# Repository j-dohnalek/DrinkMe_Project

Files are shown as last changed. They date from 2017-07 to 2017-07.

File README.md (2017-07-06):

# DrinkMe
Drink Me - The talking coaster to support dementia patients. The idea to this started in March 2017 when at a university based hackathon Hacking Health. The idea was pitched by
Hillary Tetlow.

## Idea
One of the issues for people with dementia is the limited short term memory capacity. The memory problem can lead to forgetting to drink leading to reduced water intake and dehydration. The dehydration leads to further problems often leading to hospitalisation.

## Proposed Solution
The solution to this problem would be a talking coaster. The coaster would speak to the person reminding them to drink.

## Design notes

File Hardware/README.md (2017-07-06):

# Hardware

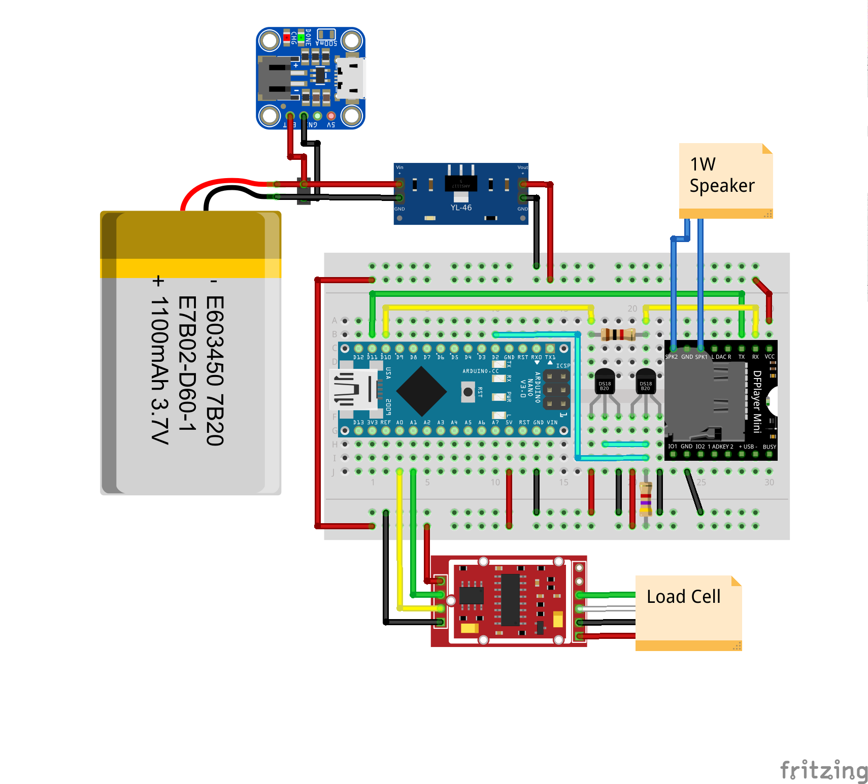
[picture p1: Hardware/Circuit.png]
Circuit


## Hardware List

### 1st stage prototype
+ Arduino Nano
+ Load Cell 2kg
+ Dallas DS18B20 Temperature Sensor
+ DFPlayer MP3 Player
+ Smartphone loudspeaker 1W
+ Micro SD Card
### 2nd stage of the prototype addition
+ DC to DC Step up converter (3.7 to 5V, 800mA to 1000mA)
+ Lipo battery charger
+ 500mAh 3.7V battery

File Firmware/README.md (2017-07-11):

## Libraries Required
+ https://github.com/aguegu/ardulibs/tree/master/hx711
+ https://github.com/milesburton/Arduino-Temperature-Control-Library
+ https://github.com/DFRobot/DFRobotDFPlayerMini/archive/1.0.1.zip

## DS18B20 temperature sensors
+ index 0: DS18B20 for external temperature
+ index 1: DS18B20 leading to the upper platform

## Sound Files
Generated using http://www.fromtexttospeech.com/

+ 001.mp3 - Spoken text "Please put the drink back onto the coaster"
+ 002.mp3 - Spoken text "It is a long time since you had a drink, please take a drink"
+ 003.mp3 - Beep sound to alarm the person from http://soundbible.com/1252-Bleep.html

## Minimum Features
+ Measure weight
+ Measure temperature under the cup and around the environment
+ Battery operated (Target of minimum of 12 hours)
+ Play MP3 reasonably loud
+ Distinguish between cold and warm drinks

## Global Variables

```C
// Temperature difference between 1 full cycle measurements. The warm drink will 
// increase the measured temperature in one cycle above the value in the variable
// triggering warm drink sub-process
double temperatureRise = 1.5; // degree C

// The weight measured by the load cell has to exceed the trigger weight in order
// to start further sub-processes
int triggerWeight = 350; // grams

// The minimum weight on the platform after which the platform is considerate
// as empty
int minimumWeightOnPlatform = 50; // grams

// The cup will loose on weight as the person drink from the cup the target
// reduction of the cup is to decrease the weight by 30% which is reasonable
// portion of the liquid in the mug, or glass
float drinkWeightReduction = 0.3;

// One cycle - check the weight and temperature determine if there is a
// weight on the platform
unsigned long oneCycle = MINUTE;

// Assuming if the drink is cold it is reasonable that a person
// should drink every 15 min until the cup until the target is met
// validation will come later in the product development
unsigned long delayBetweenColdDrinks = 15 * MINUTE;
```

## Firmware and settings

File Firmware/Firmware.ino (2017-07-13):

/**
 * DrinkMeProject.ino
 * Copyright (C) 2017 Jiri Dohnalek
 *
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
 */

// TODO - Consider the problem when the user does not places the cup
//        back onto the coaster, how to implement a reminder to notify
//        the user to return the cup on the coaster

// TODO - Consider adding second DS18B20 temperature sensor to calculate
//        the time for the drink to cool with higher precision

// TODO - How to handle the gap between the drinking and putting it back
//        onto the coaster. How long? What is the procedure?

// TODO - Consider https://github.com/bogde/HX711 library with the ability
//        to send the HX711 chip to lower power


#include <hx711.h>
#include <OneWire.h>
#include <DallasTemperature.h>
#include <math.h>
#include "Arduino.h"
#include "SoftwareSerial.h"
#include "DFRobotDFPlayerMini.h"


// MP3 Player configuration
// ------------------------

SoftwareSerial dftPlayerSoftwareSerial(10, 11); // RX, TX
DFRobotDFPlayerMini DFPlayer;

// Newton laws of cooling
// ----------------------

// t0 = (DS18B20) surrounding temperature
double t0; 
// t1 = initial liquid temperature (estimate)
double t1=80.00;
// t2 = desired temperature of the liquid (estimate)
double t2=48.00;

// Constant to use for the calculation
const double k = 0.056;

// Arduino implementation
// t -> time it takes to reach target temperature
// t = (-1.0/k) * log((t2-t0)/(t1-t0))


// DS18B20 configuration
// ----------------

#define ONE_WIRE_BUS 2
OneWire oneWire(ONE_WIRE_BUS);
DallasTemperature sensors(&oneWire);


// Load cell configuration
// -----------------------

Hx711 scale(A1, A0);

// Calibration process:
// https://github.com/aguegu/ardulibs/tree/master/hx711
long loadCellOffset = 8277286;
float loadCellRatio = -1045;


// Miscelaneous variables
// ----------------------


// Define 1 second
#define SECOND 1000UL


// Define 1 minute
#define MINUTE (SECOND * 60UL)


// The initial volume for the MP3 Player module
int initialVolume = 30;


// Stores the temperature measurement from the previous temperature reading
// for comparison
double previousTemperature = 0; // degree C


// Temperature difference between 1 full cycle measurements. The warm drink will 
// increase the measured temperature in one cycle above the value in the variable
// triggering warm drink sub-process
double temperatureRise = 1.5; // degree C


// The weight measured by the load cell has to exceed the trigger weight in order
// to start further sub-processes
int triggerWeight = 350; // grams


// The minimum weight on the platform after which the platform is considerate
// as empty
int minimumWeightOnPlatform = 50; // grams


// The cup will loose on weight as the person drink from the cup the target
// reduction of the cup is to decrease the weight by 30% which is reasonable
// portion of the liquid in the mug, or glass
float drinkWeightReduction = 0.3;


// One cycle - check the weight and temperature determine if there is a
// weight on the platform
unsigned long oneCycle = MINUTE;


// Assuming if the drink is cold it is reasonable that a person
// should drink every 15 min until the cup until the target is met
// validation will come later in the product development
unsigned long delayBetweenColdDrinks = 15 * MINUTE;


// --------------
// Setup Function
// --------------

void setup() {


  // Start communication over serial for debuging
  Serial.begin(115200);


  // Start the communication with the MP3 Player
  // -------------------------------------------

  Serial.println(F("Initializing DFPlayer"));
  // Start communication over serial with DFPlayer
  dftPlayerSoftwareSerial.begin(9600);

  if (!DFPlayer.begin(dftPlayerSoftwareSerial)) {
    Serial.println(F("Unable to begin DFPlayer"));
    while(true);
  }

  Serial.println(F("DFPlayer Mini Active."));
  // Set the volume
  DFPlayer.volume(initialVolume);


  Serial.println(F("Setting up device DS18B20 and Load Cell"));

  // Start the communication with DS18B20
  // ------------------------------------

  sensors.begin();
  Serial.println(F("DS18B20 ready"));

  // Read initial temperature
  sensors.requestTemperatures();
  previousTemperature = (double)sensors.getTempCByIndex(1);


  // Start communication to the load Cell
  // ------------------------------------

  scale.setOffset(loadCellOffset);
  scale.setScale(loadCellRatio);
  Serial.println(F("Load Cell ready"));

}

// --------------
// Loop Function
// --------------

void loop() {

  // Obtain latest temperature
  int drinkWeight = (int)round(scale.getGram());

  Serial.print(F("w="));
  Serial.print(drinkWeight);

  // Send the command to get temperature
  sensors.requestTemperatures();

  // Obtain latest temperature
  double currentTemp = (double)sensors.getTempCByIndex(1);

  // Calculte the temperature difference between now and previous cycle
  double temperatureDifference = currentTemp - previousTemperature;

  Serial.print(F("  t (act.)="));
  Serial.print(currentTemp);

  Serial.print(F("  t (diff.)="));
  Serial.println(temperatureDifference);

  // Threshold to trigger the start of the subroutines
  if(drinkWeight > triggerWeight){

    // If there is a rise in temperature, between the previous reading and
    if(temperatureDifference > temperatureRise){
      Serial.println(F("Started warm drink subroutine"));
      warmDrinkSubRoutine();
      Serial.println(F("End of warm drinking sequence"));
    }
    // Otherwise drink is cold, start cold subroutine
    else{
      Serial.println(F("Started cold drink subroutine"));
      coldDrinkSubRoutine();
      Serial.println(F("End of cold drinking sequence"));
    }
  }

  // Record the current temperature on the end of the cycle to monitor the
  // temperature difference for controlling the hot or cold drink
  previousTemperature = currentTemp;

  Serial.println(F("-- |CYCLE END| --"));

  // In order to save power run the device one time every x times every minute.
  delay(oneCycle);
}

void warmDrinkSubRoutine(){

  int drinkWeight = (int)round(scale.getGram());

  // The cup will loose on weight as the person drink from the cup
  // the target reduction of the cup is to decrease the weight by 40%
  int targetdrinkWeight = (int)(drinkWeight * (1-drinkWeightReduction));
    
  // external temperature
  t0 = (double)sensors.getTempCByIndex(0);

  // calculate the delay until the drink will be in the
  // ideal temperature according to newton laws of cooling
  unsigned long coolingDelay = (unsigned long) ((-1.0/k) * log((t2-t0)/(t1-t0))) * 1000;
  delay(coolingDelay);

  Serial.println(F("Reminding the user to drink"));
  // Play the sound before voice command
  DFPlayer.play(3);
  delay(3 * SECOND);

  // Play the sound of the voice command to remind the user to drink
  DFPlayer.play(2);
  delay(6 * SECOND);
  DFPlayer.stop();

  // Start the cold subroutine with initial reminder to drink

  while(true){
    break;
  }

}

/**
 * Handle the placement of the cold drink on the platform including all the
 * subsequent actions
 */
void coldDrinkSubRoutine(){

  // Update the weight of the cup
  int drinkWeight = (int)round(scale.getGram());

  // Target weight to stop the subroutine
  int targetdrinkWeight = (int)(drinkWeight * (1-drinkWeightReduction));

  Serial.print(F("Target cup weight: "));
  Serial.println(targetdrinkWeight);

  while(true){

    // Measure the weight of the cup
    drinkWeight = (int)round(scale.getGram());

    Serial.print(F("Last measured weight: "));
    Serial.println(drinkWeight);

    // Stop the subroutine when the person have met the required target but
    // the cup is still on the the coaster
    if(drinkWeight <= targetdrinkWeight && drinkWeight > minimumWeightOnPlatform){
      Serial.println(F("End of cold drinking sequence"));
      return;
    }

    Serial.println(F("Wait 15 minutes"));
	  // Delay the notification between the drinks
    delay(delayBetweenColdDrinks);

    // Update the latest cup weight
    drinkWeight = (int)round(scale.getGram());
    Serial.print(F("Last measured weight: "));
    Serial.println(drinkWeight);

    // stop the subroutine when the person have met the required target but
    // the cup is still on the the coaster
    if(drinkWeight <= targetdrinkWeight && drinkWeight > minimumWeightOnPlatform){
      return;
    }

    while(true){

      Serial.println(F("Reminding the user to drink"));
      // Play the sound before voice command
      DFPlayer.play(3);
      delay(3 * SECOND);

      // Play the sound of the voice command to remind the user to drink
      DFPlayer.play(2);
      delay(6 * SECOND);
      DFPlayer.stop();

      Serial.println(F("Waiting for user to pick up the cup"));
      // Wait small amount of time for the user
      // to pick up the cup from the platform
      delay(10 * SECOND);

      // Measure the weight of the cup
      // The user have picked up the cup from the platform if the
      // weight recorded on the platform is less than 50g
      drinkWeight = (int)round(scale.getGram());
      Serial.print(F("Last measured weight: "));
      Serial.println(drinkWeight);
      
      if(drinkWeight < minimumWeightOnPlatform){
        
        Serial.println(F("Drinking detected..."));
        
        // Give time to the user to drink the beverage
        delay(30 * SECOND);

        drinkWeight = (int)round(scale.getGram());

        // Handle when the user did not returned the cup onto the platform
        handleEmptyPlatform(drinkWeight);

        break;
      }
    }
  }

}


/**
 * The person have probably taken the cup but have not returned it onto
 * the platform, notify the user to return the cup onto platform
 *
 * @param weight, latest weight reading
 */
void handleEmptyPlatform(int weight){

  // Check if the cup is on the platform
  while(weight < minimumWeightOnPlatform){

    Serial.println(F("Reminding user to put the drink back onto the coaster"));
    // Play the notification sound before the reminder
    DFPlayer.play(3);
    delay(3 * SECOND);

    // Play the text to remind the user to put the cup back onto the coaster
    DFPlayer.play(1);
    delay(3 * SECOND);

    // Stop the MP3 Player
    DFPlayer.stop();

    // User have placed the cup back onto the platform
    if((int)round(scale.getGram()) > minimumWeightOnPlatform){
      return;
    }
    else{
      delay(10 * SECOND);
    }
  }
}

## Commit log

2017-06-29 Fritzing Schematics
    Version 1 of the circuit schematics
2017-06-29 Fritzing Schematic
    [Circuit.fzz]
2017-06-29 Organise the files
    [Circuit.fzz]
2017-06-30 Fixed linked to the image of the circuit
2017-07-06 Update timing, timing reset
    Added improved meaningful setting of the time delay, removed reset millis() function from the sketch while reading http://forum.arduino.cc/index.php?topic=116038.0. The method is not required if the sketch is not required to do something in the meantime while waiting.
2017-07-06 Added all required components
    [Circuit.fzz]
2017-07-06 Prototype with all components
2017-07-13 Attempt to fix issue with placing the cup back to coaster
    [Firmware.ino]

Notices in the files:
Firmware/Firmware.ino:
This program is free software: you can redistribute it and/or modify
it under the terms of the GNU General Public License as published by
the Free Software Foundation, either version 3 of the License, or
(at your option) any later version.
